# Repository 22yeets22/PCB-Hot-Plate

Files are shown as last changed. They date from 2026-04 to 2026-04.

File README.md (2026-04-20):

<h1 align="center">
  PCB Hot Plate
  <br>
</h1>

<h4 align="center">
A 140W universal USB-C powered PCB Hot Plate!
</h4>
<br>

<div align="center">

| Controller | Heating Element |
| --- | --- |
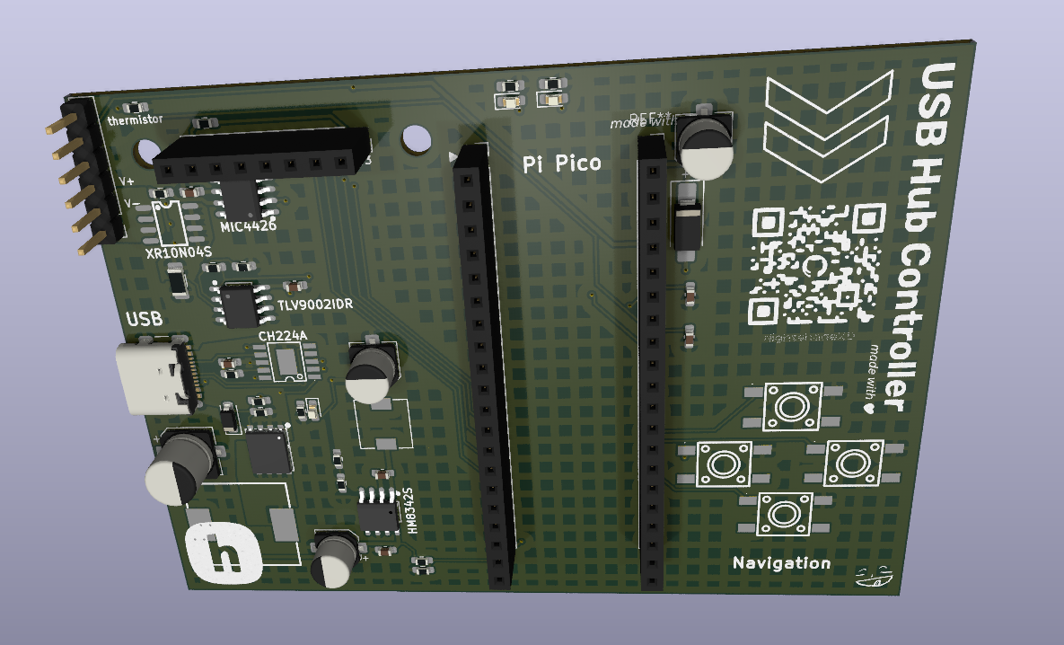
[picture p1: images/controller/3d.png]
Controller PCB 3D
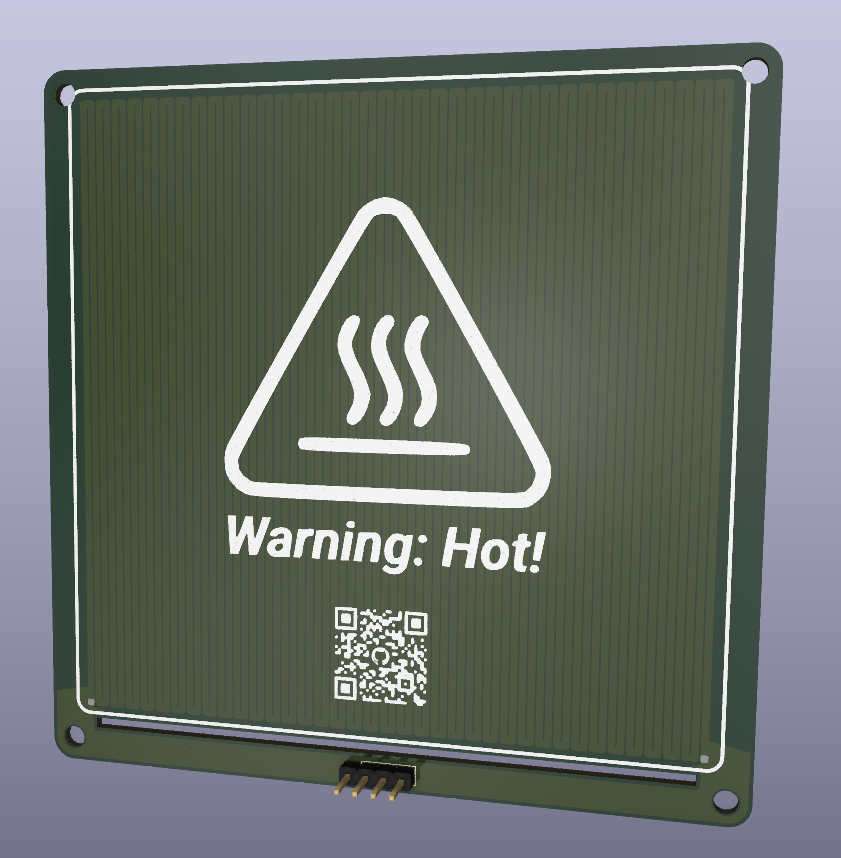
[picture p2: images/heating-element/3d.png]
Heating Element 3D
|  |  |

</div>

## Description

A 140W USB-C-powered PCB hot plate for precise heating, such as for solder reflow. It uses a USB-C power input for accessibility and uses an aluminium PCB heating element driven a switching MOSFET, along with thermistors to monitor temperature, USB-C negotiation, and real-time current/voltage monitoring.

## Motivation

My motivation for this project was to create a low-cost, customizable, fully controllable PCB hotplate for electronics work, like soldering or heating stuff up. I thought that other hotplates online were very expensive and lacked the power I wanted. By designing a custom solution, I made a new hot plate capable of higher wattage (140W) and better flexibility.

## Features

- Powered by the pi pico
- Supports 140W (28V, 5A) from USB-C
- Compatible with any usb-c device
- 1.8 inch LCD screen
- 4 buttons to control
- LEDS for visualization
- Seperated heating element and controller for ease of replacement
- Temperature control

## BOM

| Name | Purpose | Quantity | Total Cost (USD) | Link | Distributor |
| --- | --- | --- | --- | --- | --- |
| 1.8in LCD Screen | See navigation + temp + UI | 1 | 3.79 | https://www.aliexpress.us/item/3256811557250210.html | Aliexpress |
| 2.54mm Pin Headers - Male | Fill in the 1x6 and the 1x4 pin headers | 1 | 4.19 | https://www.aliexpress.us/item/3256806547306536.html | Aliexpress |
| 2.54mm Pin Headers - Female | Breakaway headers to fill in the 1x8 spot for the LCD Screen | 1 | 4.66 | https://www.aliexpress.us/item/3256806547306536.html | Aliexpress |
| PCB Heating Element | The actual heating element to heat it up. | 10 | 5.00 | | JLCPCB |
| Controller PCB | The actual fr-4 pcb to control all of this | 10 | 5.00 | | JLCPCB |
| Diode Independent 40V 3A Surface Mount SMA(DO-214AC) | | 20 | 0.66 | | GOODWORK |
| 1uF ±10% 50V Ceramic Capacitor X5R 0603 | | 50 | 0.39 | | Samsung Electro-Mechanics |
| 100nF ±10% 50V Ceramic Capacitor X7R 0603 | | 100 | 0.31 | | YAGEO |
| 22uF ±20% 35V Aluminum Electrolytic Capacitors 2000hrs@105℃ | | 40 | 1.28 | | KNSCHA |
| 49.9kΩ ±1% 100mW 0603 Thick Film Resistor | | 100 | 0.15 | | UNI-ROYAL |
| 100uF ±20% 35V Aluminum Electrolytic Capacitors 2800hrs@105℃ | | 20 | 0.78 | | DMBJ |
| 5pA 2 2V/us 1MHz Rail-to-Rail Input, Rail-to-Rail Output SOIC-8 Instrumentation, Op Amps, Buffer Amps RoHS | | 10 | 1.18 | | TI |
| Buck Switching Regulator IC Adjustable 0.8V~24V 1 Output 2A SOP-8-EP | | 10 | 1.19 | | GATEMODE |
| 5V~18V 1.5A SOIC-8 Gate Drivers RoHS | | 10 | 3.12 | | Tokmas |
| 3A 6.8uH ±20% 40mΩ 3.3A Magnetic Shielded Inductor SMD,6x6mm | | 10 | 0.37 | | GUDIAN |
| 100mW 56kΩ 75V Thick Film Resistor ±1% 0603 | | 100 | 0.16 | | YAGEO |
| 210kΩ ±1% 100mW 0603 Thick Film Resistor | | 100 | 0.15 | | UNI-ROYAL |
| 82kΩ ±1% 100mW 0603 Thick Film Resistor | | 100 | 0.11 | | FOJAN |
| 100mW 1kΩ 75V Thick Film Resistor ±1% 0603 | | 100 | 0.15 | | YAGEO |
| 10mΩ 1W ±1% 1206 Chip Resistor | | 10 | 0.47 | | JIERR |
| 10Ω ±1% 100mW 0603 Thick Film Resistor | | 100 | 0.10 | | FOJAN |
| 100mW 10kΩ 75V Thick Film Resistor ±1% 0603 | | 100 | 0.15 | | YAGEO |
| 5.1kΩ ±1% 100mW 0603 Thick Film Resistor | | 100 | 0.12 | | FOJAN |
| 100mW 330Ω 75V Thick Film Resistor ±1% 0603 | | 100 | 0.15 | | YAGEO |
| P-Channel 40V 25A Surface Mount PDFN5060-8L | | 10 | 1.06 | | XNRUSEMI |
| N-Channel 40V 10A Surface Mount SOP-8 | | 10 | 0.77 | | XNRUSEMI |
| 10A 22uH ±20% SMD Inductor | | 10 | 3.22 | | XR |
| Tactile Switch SPST 180gf 6mm x 6mm SMD | | 40 | 2.28 | | Yuandi |
| Female Header 20 Position 2.54mm Pitch | | 20 | 2.25 | | HanElectricity |
| USB-C Receptacle Connector 16 Position SMD | | 10 | 1.85 | | Korean Hroparts Elec |
| Zener Diode 15V 500mW SOD-123 | | 50 | 0.73 | | MDD |
| Emerald Green LED 0603 | | 100 | 0.61 | | YONGYUTAI |

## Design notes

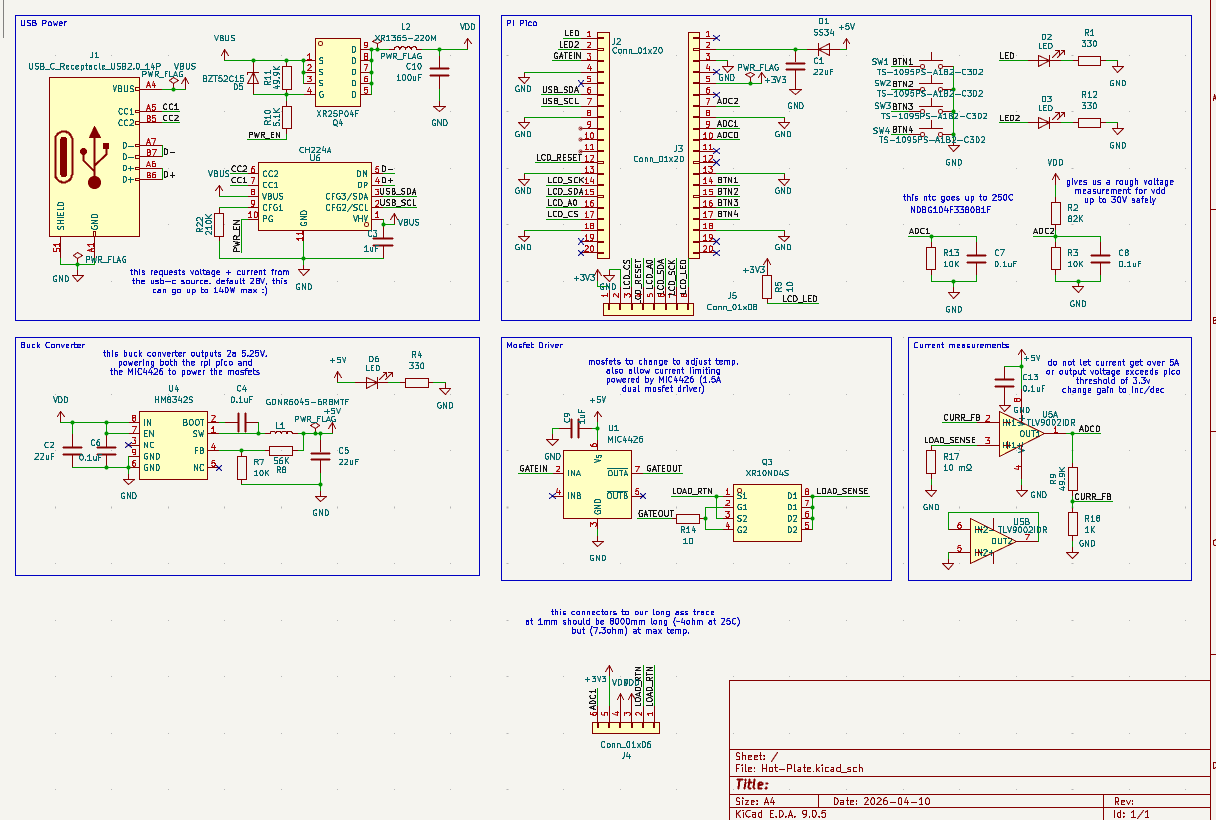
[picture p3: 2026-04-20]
images/controller/schematic.png

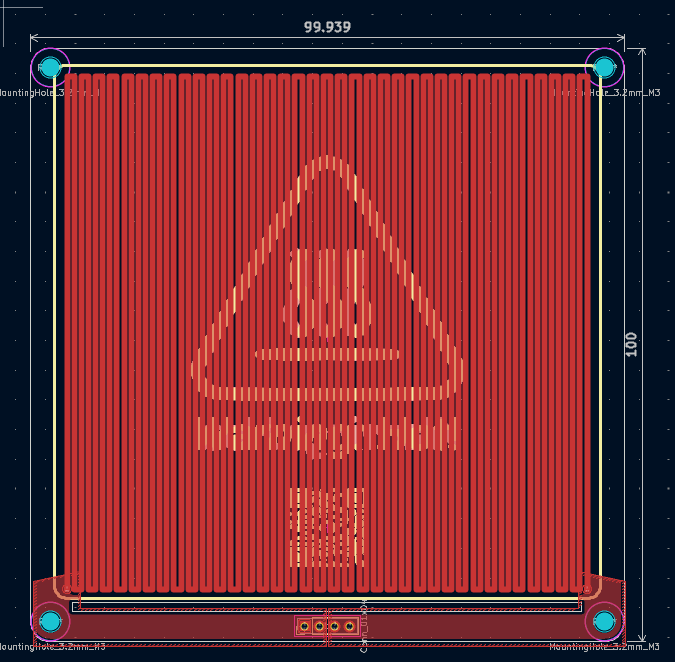
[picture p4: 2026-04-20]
images/heating-element/pcb.png

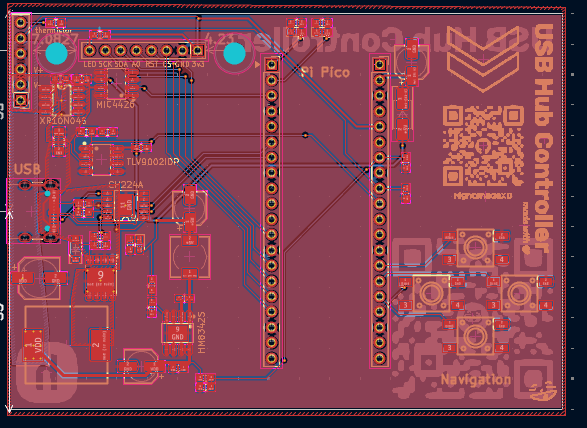
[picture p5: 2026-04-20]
images/controller/pcb.png

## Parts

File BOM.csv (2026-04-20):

Name | Purpose | Quantity | Total Cost (USD) | Link | Distributor
Pi Pico | To plug into the pico socket to act as the microcontroller | 5 | 11.60 | https://www.aliexpress.us/item/3256808388173491.html | Aliexpress
1.8in LCD Screen | See navigation + temp + UI | 5 | 18.95 | https://www.aliexpress.us/item/3256811557250210.html | Aliexpress
2.54mm Pin Headers - Male | Fill in the 1x6 and the 1x4 pin headers | 1 | 4.19 | https://www.aliexpress.us/item/3256806547306536.html | Aliexpress
2.54mm Pin Headers - Female | Breakaway headers to fill in the 1x8 spot for the LCD Screen | 1 | 4.66 | https://www.aliexpress.us/item/3256806547306536.html | Aliexpress
PCB Heating Element | The actual heating element to heat it up. | 10 | 5.00 |  | JLCPCB
Controller PCB | The actual fr-4 pcb to control all of this | 10 | 5.00 |  | JLCPCB
1uF ±10% 50V Ceramic Capacitor X5R 0603 |  | 50 | 0.39 |  | Samsung Electro-Mechanics
100nF ±10% 50V Ceramic Capacitor X7R 0603 |  | 100 | 0.31 |  | YAGEO
22uF ±20% 35V Aluminum Electrolytic Capacitors 2000hrs@105℃ |  | 40 | 1.28 |  | KNSCHA
49.9kΩ ±1% 100mW 0603 Thick Film Resistor |  | 100 | 0.15 |  | UNI-ROYAL
100uF ±20% 35V Aluminum Electrolytic Capacitors 2800hrs@105℃ |  | 20 | 0.78 |  | DMBJ
5pA 2 2V/us 1MHz Rail-to-Rail Input, Rail-to-Rail Output SOIC-8 Instrumentation, Op Amps, Buffer Amps RoHS |  | 10 | 1.18 |  | TI
Buck Switching Regulator IC Adjustable 0.8V~24V 1 Output 2A SOP-8-EP |  | 10 | 1.19 |  | GATEMODE
5V~18V 1.5A 1.5A SOIC-8 Gate Drivers RoHS |  | 10 | 3.12 |  | Tokmas
3A 6.8uH ±20% 40mΩ 3.3A Magnetic Shielded Inductor SMD,6x6mm Fixed Inductors RoHS |  | 10 | 0.37 |  | GUDIAN
100mW 56kΩ 75V Thick Film Resistor ±100ppm/℃ ±1% 0603 Chip Resistor - Surface Mount RoHS |  | 100 | 0.16 |  | YAGEO
210kΩ ±1% 100mW 0603 Thick Film Resistor |  | 100 | 0.15 |  | UNI-ROYAL
82kΩ ±1% 100mW 0603 Thick Film Resistor |  | 100 | 0.11 |  | FOJAN
100mW 1kΩ 75V Thick Film Resistor ±100ppm/℃ ±1% 0603 Chip Resistor - Surface Mount RoHS |  | 100 | 0.15 |  | YAGEO
10mΩ 1W ±50ppm/℃ ±1% 1206 Chip Resistor - Surface Mount RoHS |  | 10 | 0.47 |  | JIERR
10Ω ±1% 100mW 0603 Thick Film Resistor |  | 100 | 0.10 |  | FOJAN
100mW 10kΩ 75V Thick Film Resistor ±100ppm/℃ ±1% 0603 Chip Resistor - Surface Mount RoHS |  | 100 | 0.15 |  | YAGEO
5.1kΩ ±1% 100mW 0603 Thick Film Resistor |  | 100 | 0.12 |  | FOJAN
100mW 330Ω 75V Thick Film Resistor ±100ppm/℃ ±1% 0603 Chip Resistor - Surface Mount RoHS |  | 100 | 0.15 |  | YAGEO
P-Channel 40V 25A 40.3W Surface Mount PDFN5060-8L |  | 10 | 1.06 |  | XNRUSEMI
N-Channel 40V 10A 20W Surface Mount SOP-8 |  | 10 | 0.77 |  | XNRUSEMI
10A 22uH ±20% 12A 42mΩ SMD,13.5x12.6mm Fixed Inductors RoHS |  | 10 | 3.22 |  | XR
Tactile Switch SPST 180gf 4.3mm Gull Wing 6mm x 6mm Surface Mount |  | 40 | 2.28 |  | Yuandi
Female Header 20 Position 2.54mm Pitch Single Row Through Hole -40℃~+105℃ |  | 20 | 2.25 |  | HanElectricity
USB-C (USB TYPE-C) Receptacle Connector 16 Position Surface Mount |  | 10 | 1.85 |  | Korean Hroparts Elec
Zener Diode Independent 15V 500mW Surface Mount SOD-123 |  | 50 | 0.73 |  | MDD(Microdiode Semiconductor)
Emerald Green LED Indication - Discrete 2.7V~3.2V 0603 |  | 100 | 0.61 |  | YONGYUTAI
Diode Independent 40V 3A Surface Mount SMA(DO-214AC) |  | 20 | 0.66 |  | GOODWORK

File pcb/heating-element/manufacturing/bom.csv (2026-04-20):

Designator | Footprint | Quantity | Value | LCSC Part #
J1 | PinHeader_1x04_P2.54mm_Vertical | 1 | Conn_01x04

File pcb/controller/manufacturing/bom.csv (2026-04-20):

Designator | Footprint | Quantity | Value | LCSC Part #
C1, C2, C5 | CP_Elec_5x5.4 | 3 | 22uF
C10 | CP_Elec_6.3x7.7 | 1 | 100uF
C13, C4, C6, C7, C8 | 0603 | 5 | 0.1uF
C3, C9 | 0603 | 2 | 1uF
D1 | D_SMA_Handsoldering | 1 | SS34
D2, D3, D6 | 0603 | 3 | LED
D5 | D_SOD-123 | 1 | BZT52C15
J1 | USB_C_Receptacle_GCT_USB4105-xx-A_16P_TopMnt_Horizontal | 1 | USB_C_Receptacle_USB2.0_14P
J2, J3 | PinSocket_1x20_P2.54mm_Vertical | 2 | Conn_01x20
J4 | PinHeader_1x06_P2.54mm_Vertical | 1 | Conn_01x06
J5 | PinSocket_1x08_P2.54mm_Vertical | 1 | Conn_01x08
L1 | L_6.3x6.3_H3 | 1 | GDNR6045-6R8MTF
L2 | IND-SMD_L13.5-W12.6_YSPI1335T-1R0M | 1 | XR1365-220M | C41384053
Q3 | SOP-8_L4.9-W3.9-P1.27-LS6.0-BL | 1 | XR10N04S | C42456793
Q4 | PDFN-8_L5.8-W5.0-P1.27-LS6.1-BL | 1 | XR25P04F | C42456987
R1, R12, R4 | 0603 | 3 | 330
R10 | 0603 | 1 | 5.1K
R11, R9 | 0603 | 2 | 50K
R13, R3, R7 | 0603 | 3 | 10K
R14, R5 | 0603 | 2 | 10
R17 | 1206 | 1 | 10 mΩ
R18 | 0603 | 1 | 1K
R2 | 0603 | 1 | 82K
R22 | 0603 | 1 | 210K
R8 | 0603 | 1 | 56K
SW1, SW2, SW3, SW4 | KEY-SMD_4P-L6.0-W6.0-P3.90-LS9.0 | 4 | TS-1095PS-A1B2-C3D2 | C2834918
U1 | SOIC-8_L4.9-W3.9-P1.27-LS6.0-BL | 1 | MIC4426 | C398360
U4 | ESOP-8_L4.9-W3.9-P1.27-LS6.0-BL-EP-1 | 1 | HM8342S | C46634661
U5 | SOIC-8_L4.9-W3.9-P1.27-LS6.0-BL | 1 | TLV9002IDR | C398360
U6 | ESSOP-10_L4.9-W3.9-P1.0-LS6.0-TL-EP | 1 | CH224A | C42459160

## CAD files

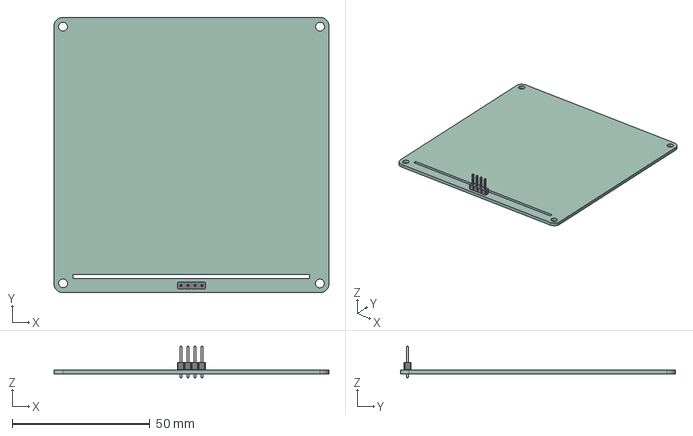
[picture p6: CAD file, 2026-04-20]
Heating-Element.step
99.9 x 100.0 x 11.5 mm
PinHeader_1x04_P2.54mm_Vertical
Hot-Plate-Board_PCB

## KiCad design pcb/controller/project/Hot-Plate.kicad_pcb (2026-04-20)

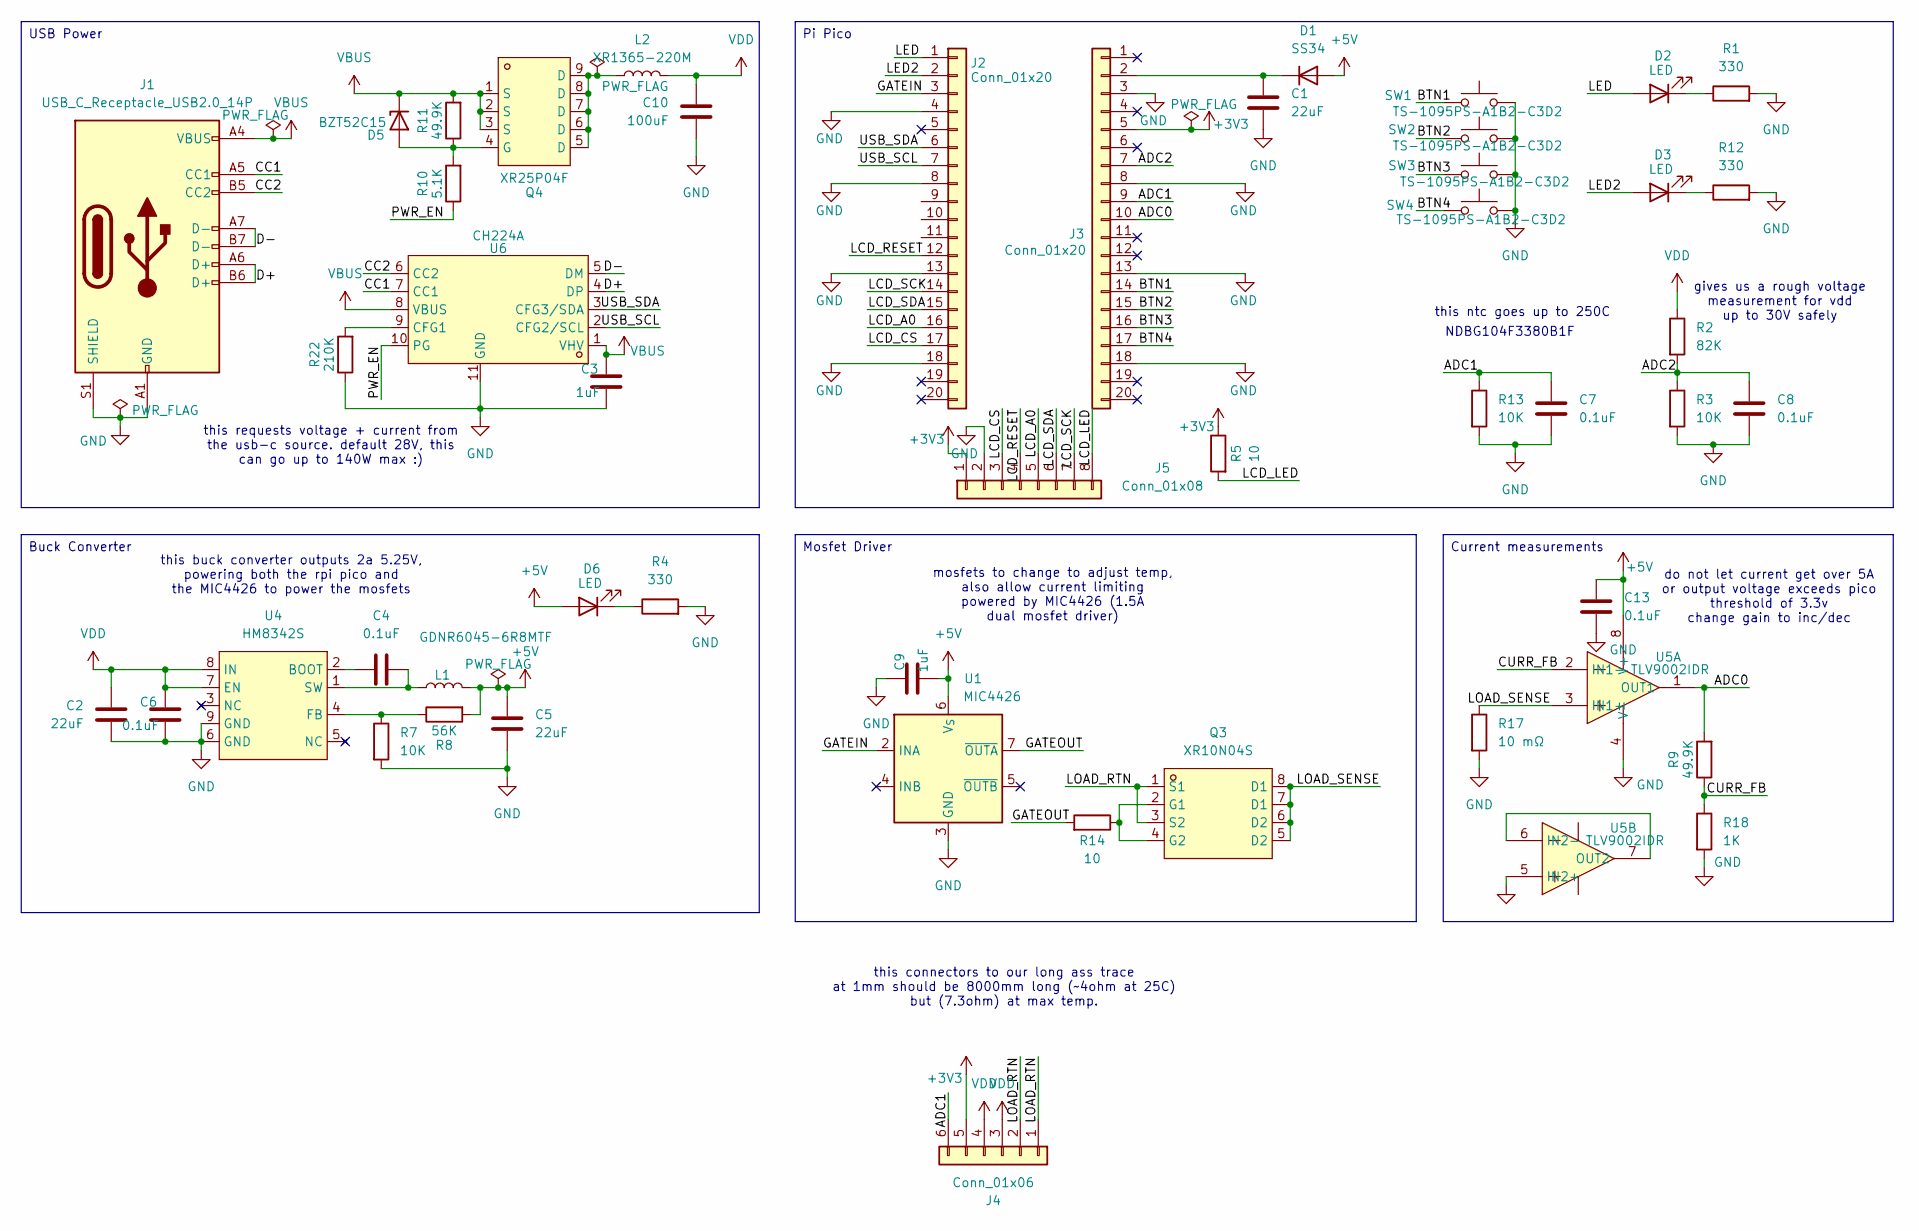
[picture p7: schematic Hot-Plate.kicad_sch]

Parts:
C1, C2, C5: 22uF; CP_Elec_5x5.4
C3, C9: 1uF; C_0603_1608Metric_Pad1.08x0.95mm_HandSolder
C4, C6, C7, C8, C13: 0.1uF; C_0603_1608Metric_Pad1.08x0.95mm_HandSolder
C10: 100uF; CP_Elec_6.3x7.7
D1: SS34; D_SMA_Handsoldering
D2, D3, D6: LED; LED_0603_1608Metric_Pad1.05x0.95mm_HandSolder
D5: BZT52C15; D_SOD-123
J1: USB_C_Receptacle_USB2.0_14P; USB_C_Receptacle_GCT_USB4105-xx-A_16P_TopMnt_Horizontal
J2, J3: Conn_01x20; PinSocket_1x20_P2.54mm_Vertical
J4: Conn_01x06; PinHeader_1x06_P2.54mm_Vertical
J5: Conn_01x08; PinSocket_1x08_P2.54mm_Vertical
L1: GDNR6045-6R8MTF; L_6.3x6.3_H3
L2: XR1365-220M; IND-SMD_L13.5-W12.6_YSPI1335T-1R0M
Q3: XR10N04S; SOP-8_L4.9-W3.9-P1.27-LS6.0-BL; MPN XR10N04S; LCSC Part C42456793
Q4: XR25P04F; PDFN-8_L5.8-W5.0-P1.27-LS6.1-BL; MPN XR25P04F; LCSC Part C42456987
R1, R4, R12: 330; R_0603_1608Metric_Pad0.98x0.95mm_HandSolder
R2: 82K; R_0603_1608Metric_Pad0.98x0.95mm_HandSolder
R3, R7, R13: 10K; R_0603_1608Metric_Pad0.98x0.95mm_HandSolder
R5, R14: 10; R_0603_1608Metric_Pad0.98x0.95mm_HandSolder
R8: 56K; R_0603_1608Metric_Pad0.98x0.95mm_HandSolder
R9, R11: 49.9K; R_0603_1608Metric_Pad0.98x0.95mm_HandSolder
R10: 5.1K; R_0603_1608Metric_Pad0.98x0.95mm_HandSolder
R17: 10 mΩ; R_1206_3216Metric_Pad1.30x1.75mm_HandSolder
R18: 1K; R_0603_1608Metric_Pad0.98x0.95mm_HandSolder
R22: 210K; R_0603_1608Metric_Pad0.98x0.95mm_HandSolder
SW1, SW2, SW3, SW4: TS-1095PS-A1B2-C3D2; KEY-SMD_4P-L6.0-W6.0-P3.90-LS9.0
U1: MIC4426; SOIC-8_L4.9-W3.9-P1.27-LS6.0-BL
U4: HM8342S; ESOP-8_L4.9-W3.9-P1.27-LS6.0-BL-EP-1; MPN HM8342S; LCSC Part C46634661
U5: TLV9002IDR; SOIC-8_L4.9-W3.9-P1.27-LS6.0-BL; MPN TLV9002IDR; LCSC Part C398360
U6: CH224A; ESSOP-10_L4.9-W3.9-P1.0-LS6.0-TL-EP; MPN CH224A; LCSC Part C42459160

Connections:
+3V3: J3.5, J4.5, J5.1, R5.1
+5V: C5.1, C9.2, C13.2, D1.2 (A), D6.2 (A), L1.2, R8.2, U1.6 (V_{S}), U5.8 (V+)
/ADC0: J3.10, R9.2, U5.1 (OUT1)
/ADC1: C7.1, J3.9, J4.6, R13.1
/ADC2: C8.1, J3.7, R2.2, R3.1
/BTN1: J3.14, SW1.1
/BTN2: J3.15, SW2.1
/BTN3: J3.16, SW3.1
/BTN4: J3.17, SW4.1
/CC1: J1.A5 (CC1), U6.7 (CC1)
/CC2: J1.B5 (CC2), U6.6 (CC2)
/CURR_FB: R9.1, R18.1, U5.2 (IN1-)
/D+: J1.A6 (D+), J1.B6 (D+), U6.4 (DP)
/D-: J1.A7 (D-), J1.B7 (D-), U6.5 (DM)
/GATEIN: J2.3, U1.2 (INA)
/GATEOUT: R14.2, U1.7 (~OUTA)
/LCD_A0: J2.16, J5.5
/LCD_CS: J2.17, J5.3
/LCD_LED: J5.8, R5.2
/LCD_RESET: J2.12, J5.4
/LCD_SCK: J2.14, J5.7
/LCD_SDA: J2.15, J5.6
/LED: D2.2 (A), J2.1
/LED2: D3.2 (A), J2.2
/LOAD_RTN: J4.1, J4.2, Q3.1 (S1), Q3.3 (S2)
/LOAD_SENSE: Q3.5 (D2), Q3.6 (D2), Q3.7 (D1), Q3.8 (D1), R17.1, U5.3 (IN1+)
/PWR_EN: R10.1, U6.10 (PG)
/USB_SCL: J2.7, U6.2 (CFG2/SCL)
/USB_SDA: J2.6, U6.3 (CFG3/SDA)
GND: C1.2, C2.2, C3.2, C5.2, C6.2, C7.2, C8.2, C9.1, C10.2, C13.1, J1.A1 (GND), J1.A12 (GND), J1.B1 (GND), J1.B12 (GND), J1.S1 (SHIELD), J2.4, J2.8, J2.13, J2.18, J3.3, J3.8, J3.13, J3.18, J5.2, R1.2, R3.2, R4.2, R7.2, R12.2, R13.2, R17.2, R18.2, R22.1, SW1.2, SW2.2, SW3.2, SW4.2, U1.3 (GND), U4.6 (GND), U4.9 (GND), U5.4 (V-), U5.5 (IN2+), U6.11 (GND)
unnamed: C1.1, D1.1 (K), J3.2
unnamed: D2.1 (K), R1.1
unnamed: D3.1 (K), R12.1
unnamed: D5.2 (A), Q4.4 (G), R10.2, R11.1
unnamed: D6.1 (K), R4.1
unnamed: L2.2, Q4.5 (D), Q4.6 (D), Q4.7 (D), Q4.8 (D), Q4.9 (D)
unnamed: Q3.2 (G1), Q3.4 (G2), R14.1
unnamed: C4.2, U4.2 (BOOT)
unnamed: R7.1, R8.1, U4.4 (FB)
unnamed: C4.1, L1.1, U4.1 (SW)
unnamed: U5.6 (IN2-), U5.7 (OUT2)
unnamed: R22.2, U6.9 (CFG1)
VBUS: C3.1, D5.1 (K), J1.A4 (VBUS), J1.A9 (VBUS), J1.B4 (VBUS), J1.B9 (VBUS), Q4.1 (S), Q4.2 (S), Q4.3 (S), R11.2, U6.1 (VHV), U6.8 (VBUS)
VDD: C2.1, C6.1, C10.1, J4.3, J4.4, L2.1, R2.1, U4.7 (EN), U4.8 (IN)

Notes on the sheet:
this ntc goes up to 250C
do not let current get over 5A or output voltage exceeds pico threshold of 3.3v change gain to inc/dec
this requests voltage + current from the usb-c source. default 28V, this can go up to 140W max :)
NDBG104F3380B1F
this connectors to our long ass trace at 1mm should be 8000mm long (~4ohm at 25C) but (7.3ohm) at max temp.
this buck converter outputs 2a 5.25V, powering both the rpi pico and the MIC4426 to power the mosfets
mosfets to change to adjust temp, also allow current limiting powered by MIC4426 (1.5A dual mosfet driver)
gives us a rough voltage measurement for vdd up to 30V safely
Current measurements
Pi Pico
Buck Converter
USB Power
Mosfet Driver

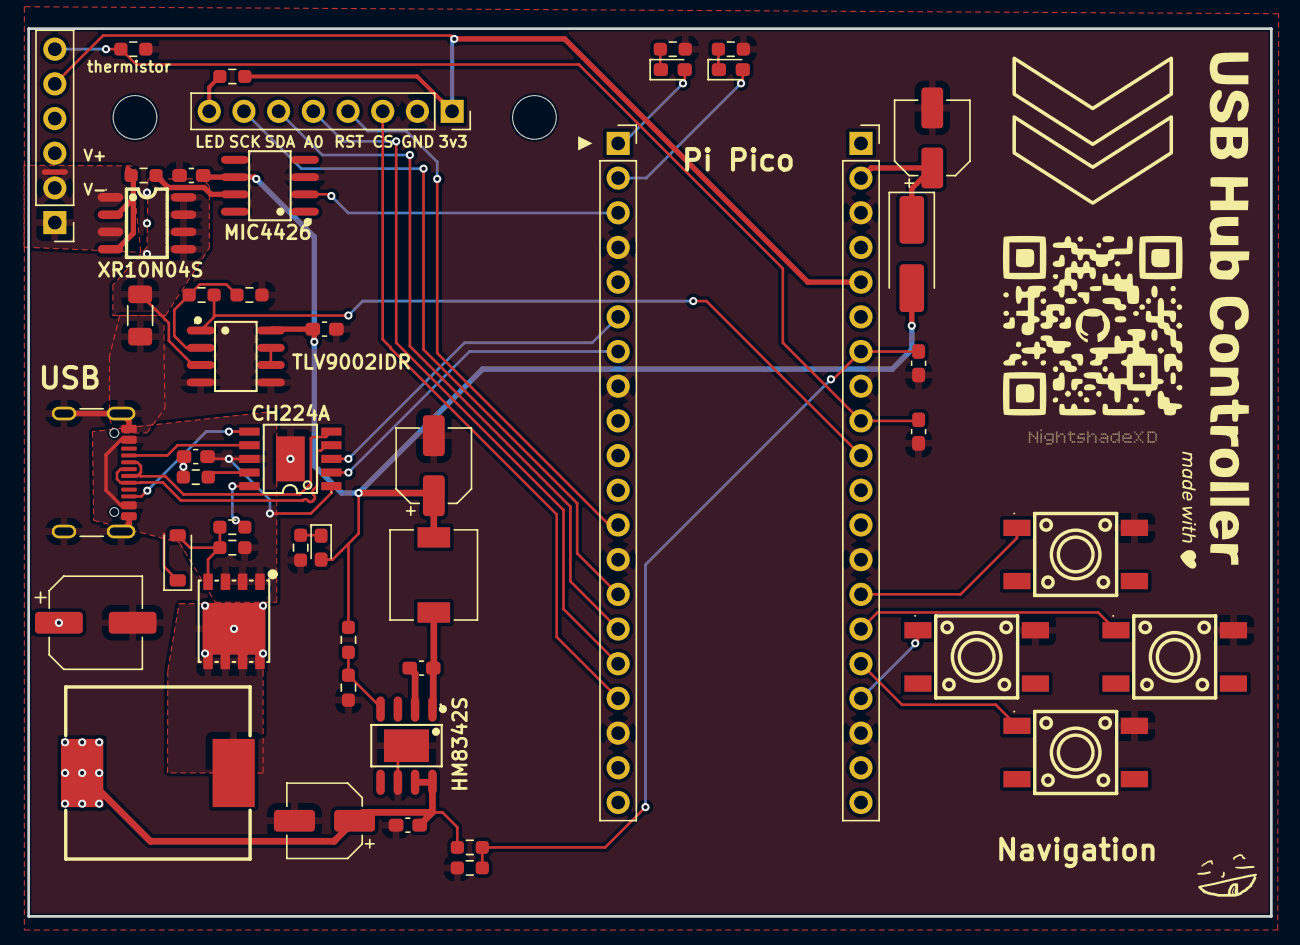
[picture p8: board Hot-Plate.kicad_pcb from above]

Board: 2 copper layers, 91.0 x 65.0 mm, 49 parts (0 on the bottom side), 44 nets.

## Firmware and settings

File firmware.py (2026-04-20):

"""
PCB Hotplate Controller Firmware
Target: Raspberry Pi Pico (RP2040) running CircuitPython
Hardware: ST7735S LCD, CH224A PD controller, NTC thermistor, TLV9002 current sense

Required CircuitPython libraries (copy to /lib on CIRCUITPY):
  - adafruit_st7735r
  - adafruit_display_text
  - adafruit_bitmap_font  (optional, for nicer fonts)
  - adafruit_bus_device
  - adafruit_display_shapes
"""

import time
import math
import board
import busio
import digitalio
import analogio
import pwmio
import displayio
import terminalio

from adafruit_st7735r import ST7735R
from adafruit_display_text import label
from adafruit_display_shapes.rect import Rect

# ─────────────────────────────────────────────
#  Pin Definitions
# ─────────────────────────────────────────────
# I2C (CH224A PD controller)
I2C_SCL_PIN  = board.GP5
I2C_SDA_PIN  = board.GP4

# PWM (MOSFET gate drive)
GATE_IN_PIN  = board.GP2

# ADC
ADC0_PIN     = board.GP26   # Current sense
ADC1_PIN     = board.GP27   # NTC temperature
ADC2_PIN     = board.GP28   # VDD voltage sense

# Buttons (active low, internal pull-up)
BTN1_PIN     = board.GP18   # Up / scroll up
BTN2_PIN     = board.GP19   # Select / Start
BTN3_PIN     = board.GP20   # Down / scroll down
BTN4_PIN     = board.GP21   # Stop / Back

# LEDs
LED1_PIN     = board.GP0
LED2_PIN     = board.GP1

# SPI / ST7735S LCD
LCD_SCK_PIN  = board.GP10
LCD_SDA_PIN  = board.GP11
LCD_DC_PIN   = board.GP12
LCD_CS_PIN   = board.GP13
LCD_RST_PIN  = board.GP9

# ─────────────────────────────────────────────
#  Hardware Constants
# ─────────────────────────────────────────────
# CH224A
CH224A_ADDR        = 0x68
CH224A_VOLT_REG    = 0x02

# ADC reference
ADC_REF_V          = 3.3
ADC_MAX            = 65535

# NTC (NDBG104F3380B1F)
NTC_NOMINAL_R      = 10000.0   # 10 kΩ at 25 °C
NTC_BETA           = 3380.0
NTC_SERIES_R       = 10000.0   # fixed resistor (low side)
NTC_NOMINAL_T      = 298.15    # 25 °C in Kelvin

# Current sense
OPAMP_GAIN         = 1 + (49900 / 1000)   # 50.9
SHUNT_R            = 0.01                  # 10 mΩ

# Voltage divider
VDIV_MULTIPLIER    = (82000 + 10000) / 10000   # 9.2×

# PWM
PWM_FREQ           = 100_000   # 100 kHz
PWM_MAX            = 65535

# ─────────────────────────────────────────────
#  PID Tuning (tune for your thermal mass)
# ─────────────────────────────────────────────
PID_KP             = 800.0
PID_KI             = 2.0
PID_KD             = 120.0
PID_I_MAX          = 30000.0   # anti-windup clamp

# ─────────────────────────────────────────────
#  Reflow Profiles
# ─────────────────────────────────────────────
# Each phase: (name, target_temp_C, duration_s, max_ramp_C_per_s)
# Ramp enforcement is handled in the PID setpoint ramp logic.
PROFILES = {
    "Sn63/Pb37": [
        ("Preheat",  100, 60,  2.0),
        ("Soak",     150, 90,  1.0),   # slow ramp into soak
        ("Ramp",     183, 30,  4.0),   # max 4 °C/s to liquidus
        ("Reflow",   210, 20,  4.0),   # peak
        ("Cooldown",  25, 60, -4.0),   # forced cool (PWM off, just tracking)
    ],
    "SAC305 (Pb-free)": [
        ("Preheat",  150, 60,  2.0),
        ("Soak",     200, 60,  1.0),
        ("Ramp",     250, 30,  4.0),
        ("Reflow",   260, 15,  4.0),
        ("Cooldown",  25, 60, -4.0),
    ],
}

PROFILE_NAMES      = list(PROFILES.keys())

# ─────────────────────────────────────────────
#  LED State Machine
# ─────────────────────────────────────────────
LED_IDLE           = 0
LED_HEATING        = 1
LED_HOT            = 2   # > 60 °C
LED_SUPER_HOT      = 3   # > 100 °C

# ─────────────────────────────────────────────
#  UI States
# ─────────────────────────────────────────────
UI_MENU            = "menu"
UI_RUNNING         = "running"
UI_MANUAL          = "manual"
UI_DONE            = "done"

# ─────────────────────────────────────────────
#  Initialise Hardware
# ─────────────────────────────────────────────

def init_hardware():
    """Initialise all peripherals and return a dict of handles."""
    hw = {}

    # ── I2C ──────────────────────────────────
    hw["i2c"] = busio.I2C(I2C_SCL_PIN, I2C_SDA_PIN, frequency=400_000)

    # ── PWM (MOSFET) ─────────────────────────
    pwm = pwmio.PWMOut(GATE_IN_PIN, frequency=PWM_FREQ, duty_cycle=0)
    hw["pwm"] = pwm

    # ── ADC ──────────────────────────────────
    hw["adc_current"] = analogio.AnalogIn(ADC0_PIN)
    hw["adc_ntc"]     = analogio.AnalogIn(ADC1_PIN)
    hw["adc_voltage"] = analogio.AnalogIn(ADC2_PIN)

    # ── Buttons ──────────────────────────────
    def make_btn(pin):
        b = digitalio.DigitalInOut(pin)
        b.direction = digitalio.Direction.INPUT
        b.pull = digitalio.Pull.UP
        return b

    hw["btn1"] = make_btn(BTN1_PIN)
    hw["btn2"] = make_btn(BTN2_PIN)
    hw["btn3"] = make_btn(BTN3_PIN)
    hw["btn4"] = make_btn(BTN4_PIN)

    # ── LEDs ─────────────────────────────────
    def make_led(pin):
        l = digitalio.DigitalInOut(pin)
        l.direction = digitalio.Direction.OUTPUT
        l.value = False
        return l

    hw["led1"] = make_led(LED1_PIN)
    hw["led2"] = make_led(LED2_PIN)

    # ── SPI / LCD ────────────────────────────
    displayio.release_displays()
    spi = busio.SPI(clock=LCD_SCK_PIN, MOSI=LCD_SDA_PIN)
    dc  = digitalio.DigitalInOut(LCD_DC_PIN)
    cs  = digitalio.DigitalInOut(LCD_CS_PIN)
    rst = digitalio.DigitalInOut(LCD_RST_PIN)

    display_bus = displayio.FourWire(spi, command=dc, chip_select=cs, reset=rst)
    # ST7735S  — 128×160, adjust rotation/dimensions to your panel orientation
    display = ST7735R(display_bus, width=128, height=160, rotation=0,
                      bgr=True, auto_refresh=False)
    hw["display"] = display

    return hw


# ─────────────────────────────────────────────
#  CH224A Power Delivery
# ─────────────────────────────────────────────

# Voltage ladder: (label, register_byte, minimum_expected_vdd)
# CH224A register 0x02 encoding per datasheet:
#   0x06 → 28 V,  0x05 → 20 V,  0x04 → 15 V,
#   0x03 → 12 V,  0x02 → 9 V,   0x01 → 5 V
CH224A_VOLTAGE_LADDER = [
    ("28V", 0x06, 26.0),
    ("20V", 0x05, 18.0),
    ("15V", 0x04, 13.5),
    ("12V", 0x03, 10.5),
    ("9V",  0x02,  8.0),
    ("5V",  0x01,  4.5),
]
# Settle time after each request before reading VDD back
CH224A_SETTLE_S = 0.15


def _ch224a_write(i2c, reg_byte):
    """Low-level: write one byte to CH224A voltage register. Returns True on success."""
    while not i2c.try_lock():
        pass
    try:
        i2c.writeto(CH224A_ADDR, bytes([CH224A_VOLT_REG, reg_byte]))
        return True
    except OSError as e:
        print(f"[CH224A] I2C error: {e}")
        return False
    finally:
        i2c.unlock()
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
